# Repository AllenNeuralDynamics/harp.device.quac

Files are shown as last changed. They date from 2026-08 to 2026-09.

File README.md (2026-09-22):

# harp.device.quac
hardware, firmware, and software source files for a Harp-compatible 4-channel Digital-to-Analog Converter.

<p align="center">
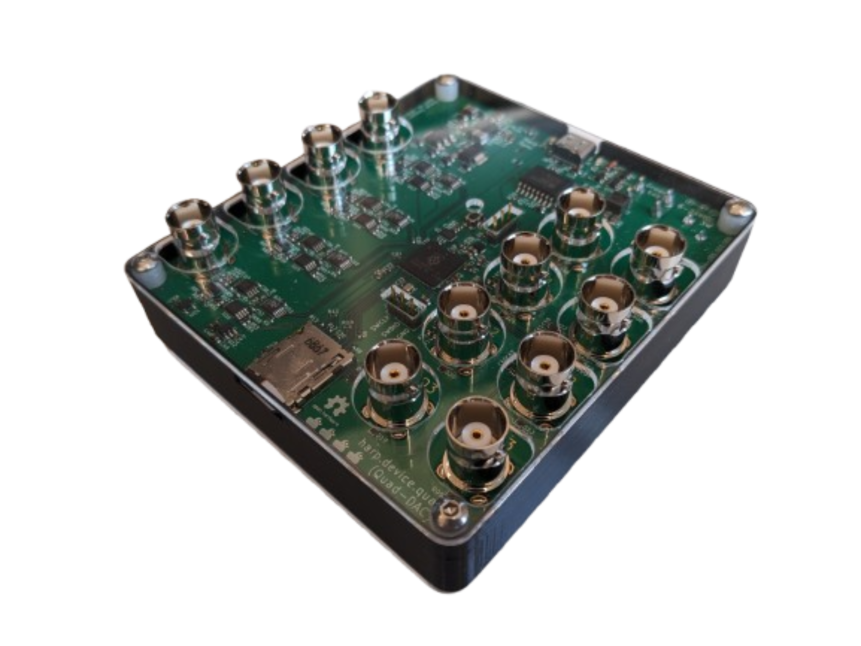
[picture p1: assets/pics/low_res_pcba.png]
  
</p>

## Specs
* Analog Output Channels: 4
* Bit depth: 16-bit
* Update Rate: 2.288 [KHz] to **500 [KHz]** (selectable per-channel)
  * this is the rate at which a new output value is selected.
* Voltage Swing: ±10 [V]
* RMS noise at the zero voltage setting: ~±2.5 [mV]
* absolute deviation from 0 [V]: ±2.5 [mV]
* Power Input: 12-24 [V]
* Power Input Plug: 2.1 x 5.5mm barrel jack (positive center)
* Reverse Polarity protected.
* Additional M4 _ground lug_ provided for de-noising.
* Open source hardware, firmware, and software.
* Cost-effective at < $300 USD to manufacture a single unit.
* Preview the hardware design online with [KiCanvas](https://kicanvas.org/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).
* Enclosure [CAD Model](https://cad.onshape.com/documents/ead77968efe820b4ecd131c1/w/59637a9e969f17bdfb8f8a49/e/516871a36164952787a658eb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)
 
### Trigger Specs
* Trigger options
  * external trigger
  * software trigger
* User-selectable external trigger mapping, i.e: any input trigger can be setup to trigger any number of analog output channels.
* True simultaneous triggering in cases where multiple waveforms are triggered at the same time.
  
### Waveform Player Specs  
The device features 3 ways to play waveforms: either through the two built-in primitive waveform generators or by playing waveforms pre-uploaded to an SD card.

#### File Player Specs  
* Max Data Storage: limited by size of SD card
* Max file length for a single file: 4GB
* File names: user-specifiable with a 32-character limit.
* Format: 16-bit Pulse Code Modulation (PCM)
  * -10 Volts corresponds to 0
  * 0 Volts corresponds to ~32768
  * 10 Volts corresponds to 65535
  
### Harp Specs
The Quac board is a fully Harp-protocol-compliant device built on top of the [Harp Pico Core](https://github.com/harp-tech/core.pico).

* Harp Device ID: 1411
* Harp Events
  * Waveform Start (per-channel)
  * Waveform Finished (per-channel)

## Alternates
The harp.device.quac board follows a legacy of many other devices that came before it.
For similar devices, have a look at:
* [Pulse Pal](https://sanworks.io/shop/viewproduct?productID=1102) by Josh Sanders.
* [PCIE-6738](https://www.ni.com/docs/en-US/bundle/pcie-6738-specs/page/specs.html) by National Instruments.

## Ordering ➡ 💸
Order fully-assembled boards directly from [PCBWay](https://www.pcbway.com/project/shareproject/harp_device_quac_quad_DAC_90dbc413.html).

These printed circuit boards are made on-demand.

## Generating Waveforms ﮩ٨ـﮩﮩ٨ـ
There are two ways to generate waveforms: either with one of two primitive waveform generators or by playing files from the SD card.
These options are referred to as waveform *Player*s.

Setting up and playing a waveform is a simple process for each Analog Output (AO) channel.
1. Specify any external input trigger conditions for the output channel.
2. Specify the waveform Player.
3. Specify the Player's settings.
4. Wait until the Player is ready (< 50[ms] of wait time for the player to apply the settings and arm the waveform).
5. Trigger the Player either via software command or by applying external input to the corresponding external input pins.

For fully worked examples of the above steps, see the examples in the [software](./software) folder.

> [!NOTE]
> While waveforms on the SD card will remain on the card until they are deleted, Player settings for any Player do not persist across device power-cycles or resets.

Player Settings are detailed below for each Player.

### Common Settings
The following settings are common to each Player.
* `cycles`: number of iterations of the current settings (will probably be 1 in most cases).
* `duration_us`: duration in microseconds to play the waveform or 0 to either *play-forever* (if the source is infinite ie: periodic functions) or *play-to-completion* (if the source is finite i.e: files on the SD card).
* `update_frequency_hz`: rate at which samples are produced (max 500 [KHz]).

### SinePlayer Waveforms

#### Settings
* `frequency_hz`: sine wave frequency in hertz
* `amplitude_volts`: "center-to-peak" amplitude in volts
* `vertical_shift_volts`: vertical shift in volts
* `normalized_phase_shift`: period shift normalized to -1.0 (max right shift) to 1.0 (max left shift)

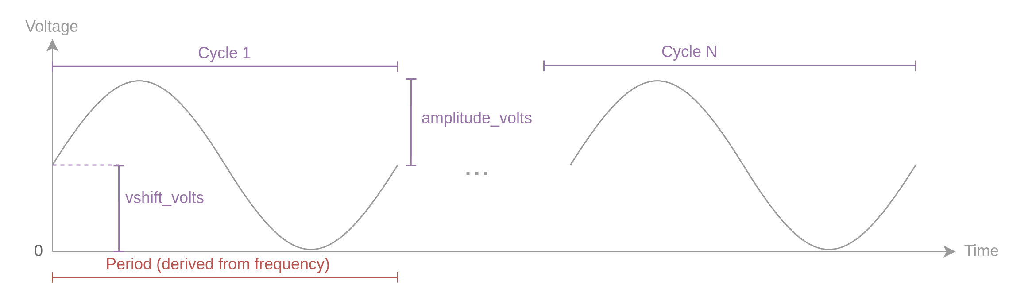
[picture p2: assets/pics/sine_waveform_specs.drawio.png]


#### Example Settings: play a 10Hz sine wave for 3 seconds
| Setting | Value | Note |
|---|---|---|
| `cycles` | 1 | play the following settings once |
| `duration_us` | 3000000 | play for 3 seconds |
| `update_frequency_hz` | 10000 | rate at which to produce new samples |
| `frequency_hz` | 10 | sine wave frequency |
| `amplitude_volts` | 0.5 | result will be 1 [V] peak-to-peak |
| `vertical_shift_volts` | 0.5 | result will span 0 [V] to 1 [V] |
| `normalized_phase_shift` | 0 | no phase shift |

#### Example Settings: play a 10Hz sine wave forever
| Setting | Value | Note |
|---|---|---|
| `cycles` | 1 | |
| `duration_us` | 0 | play forever (until aborted) |
| `update_frequency_hz` | 10000 | |
| `frequency_hz` | 10 | |
| `amplitude_volts` | 0.5 | |
| `vertical_shift_volts` | 0 | |
| `normalized_phase_shift` | 0 | |

### TrapezoidPlayer Waveforms
#### Settings
(Inherits all Common Settings and Sine Player Settings)

* `ramp_on_us`: time in microseconds to rise from lowest to peak value.
* `pulse_width_us`: the total pulse width (including ramp-on and ramp-off duration of the waveform in microseconds.
* `ramp_off_us`: time in microseconds to fall from peak to lowest value.

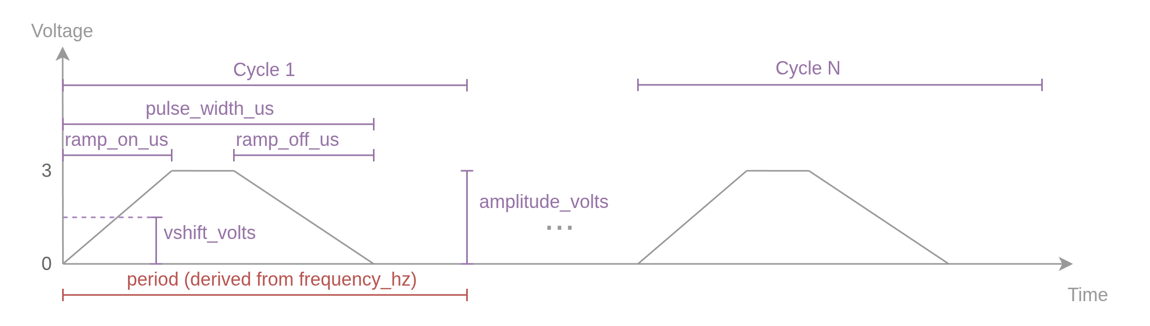
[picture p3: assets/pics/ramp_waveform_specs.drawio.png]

  
### FilePlayer Waveforms from the SD Card 💾

#### Settings
* `path`: filepath on the SD card (32-character limit max)

#### Example Settings: play a file once
| Setting | Value | Note |
|---|---|---|
| `cycles` | 1 | play the following settings once |
| `duration_us` | 0 | play the file to completion |
| `update_frequency_hz` | 500000 | max update rate (might be different depending on file). |
| `path` | channel_0.bin | assumes this file exists at the top level folder in the SD card |

#### Example Settings: play a file multiple times
| Setting | Value | Note |
|---|---|---|
| `cycles` | 3 | loop back and play the entire file 3 times |
| `duration_us` | 0 | |
| `update_frequency_hz` | 500000 | |
| `path` | channel_0.bin | |

The _quac_ board reads files in 16-bit little-endian _Pulse-Code Modulation_ (PCM) format.
There are a few options for generating waveforms in this format.

#### Upscaling Existing Files 💽
It's possible to convert existing audio files to a format compatible with the _quac_ board using `ffmpeg`.
To upscale an existing _\*.wav_ file to a 500KHz update rate, use:
```bash
ffmpeg -i example.wav -f u16le -ar 500000 output.raw
```

#### With numpy 💻
For more complicated waveforms that do not derive from an existing audio file, we recommend using numpy.

Here's an example that generates the [North American Ringing Tone](https://en.wikipedia.org/wiki/Ringing_tone#Bell_System_tones), which is the sum of a 440Hz and 480Hz sine wave.

```python
import numpy as np

NUM_SAMPLES = int(5e6) # 5 million samples @ 500KSs -> 10 seconds of data.
SAMPLES_PER_SECOND = 500000.
FULL_SCALE_RANGE = (1 << 16) - 1 # 16 bit resolution
SECONDS = NUM_SAMPLES/SAMPLES_PER_SECOND
FILENAME = f"channel_0.bin"

t = np.linspace(0, SECONDS, NUM_SAMPLES)
x = np.zeros(NUM_SAMPLES)

# make sine wave. offset it to uint16 range: 0-65535
for freq in [440, 480]:
    x += (np.sin(2 * np.pi * freq * t)+1)/2 * FULL_SCALE_RANGE/2

# Write result to file in 16-bit little-endian format.
with open(FILENAME, "wb") as file:
    x.astype("<u2").tofile(file)

```

#### Uploading Waveforms ♒︎➝💾
Currently waveforms must be uploaded to the SD card manually.

> [!WARNING]
> Power down the device before removing or inserting the SD card.

## Playing Waveforms 🎶
There are two ways to trigger a configured waveform to play: via software command or through the device's external triggers labeled **DI0**, **DI1**, **DI2**, and **DI3**.

Before triggering a waveform, you must

### Software Triggering
For fully worked examples in both Bonsai and Python, see the [software examples folder](./software).

### External Triggering
By default the device's power-on-reset behavior is setup to:
setup external triggers such that pins _DIO_ - _DI3_ correspond to playing output pins _A0_ - _A3_ respectively.

Trigger mapping is configurable!
Any input trigger can be configured to trigger any number of outputs.
To alter the trigger mapping, you must use software commands through either Bonsai or Python.

## Compatible SD Cards 💾
During normal operation, up-to-four waveforms stored on the SD card are read (interleaved) at 4MB per second.
With the extra overhead of switching between files, the SD card must be able to support read speeds ≥8MB per second.
In theory, any _Class 10 SD Card_ formatted in _FAT32 format_ should be compatible.

But since card performance can vary, here's a list of tested cards:
| Vendor | Model |
|---|---|
| Samsung | Pro Plus 8GB Smart Card |
| GIGASTONE | Industrial 8GB MLC |
| | |

## Working Principle
The following section details how the underlying firmware generates waveforms.

### Selectable Player Architecture
Each channel features a modular approach to dividing up the work of playing waveforms.
<p align="center">
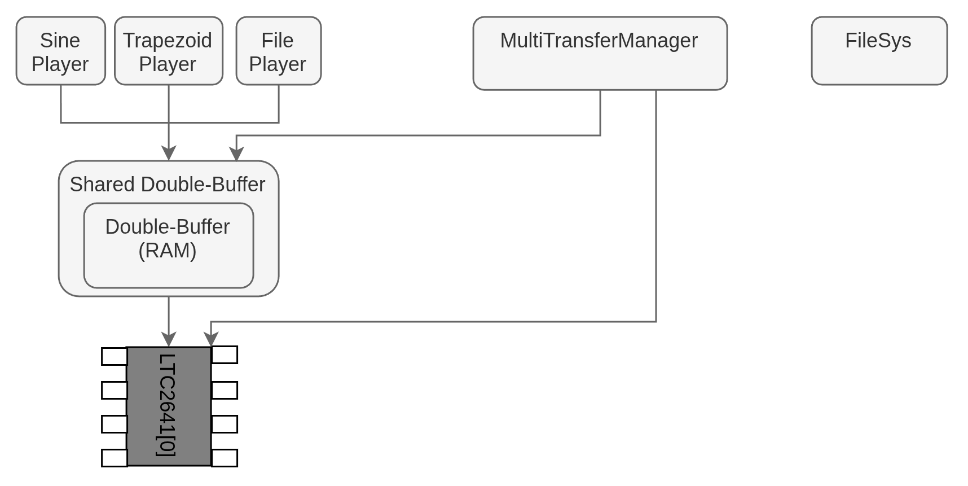
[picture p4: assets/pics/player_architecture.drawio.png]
  
</p>

The level closest to the hardware is a driver that wraps a custom PIO program to communicate over SPI to each LTC2641 DAC chip.

The next stage up is a shared double buffer and two DMA channels responsible for ensuring that the driver receives an uninterrupted, steady stream of bytes paced by a DMA Timer setup to match the user-requested playback rate.
Inspecting the state of the double buffer is implemented by reading single registers native to the Pico's DMA peripherals to eliminate the need to implement mutex locks to check multiple locations in memory concurrently.

The layer above features one of multiple ways of generating data.
These _Players_ are responsible for producing a sequence of bytes up to the limits specified by the user's waveform settings.
Each _Player_ is derived from a base class that manages sending data to the corresponding available buffer from the downstream double buffer and manages sequence arming and termination.

In the full architecture, four copies of the above pipeline exist like so:

<p align="center">
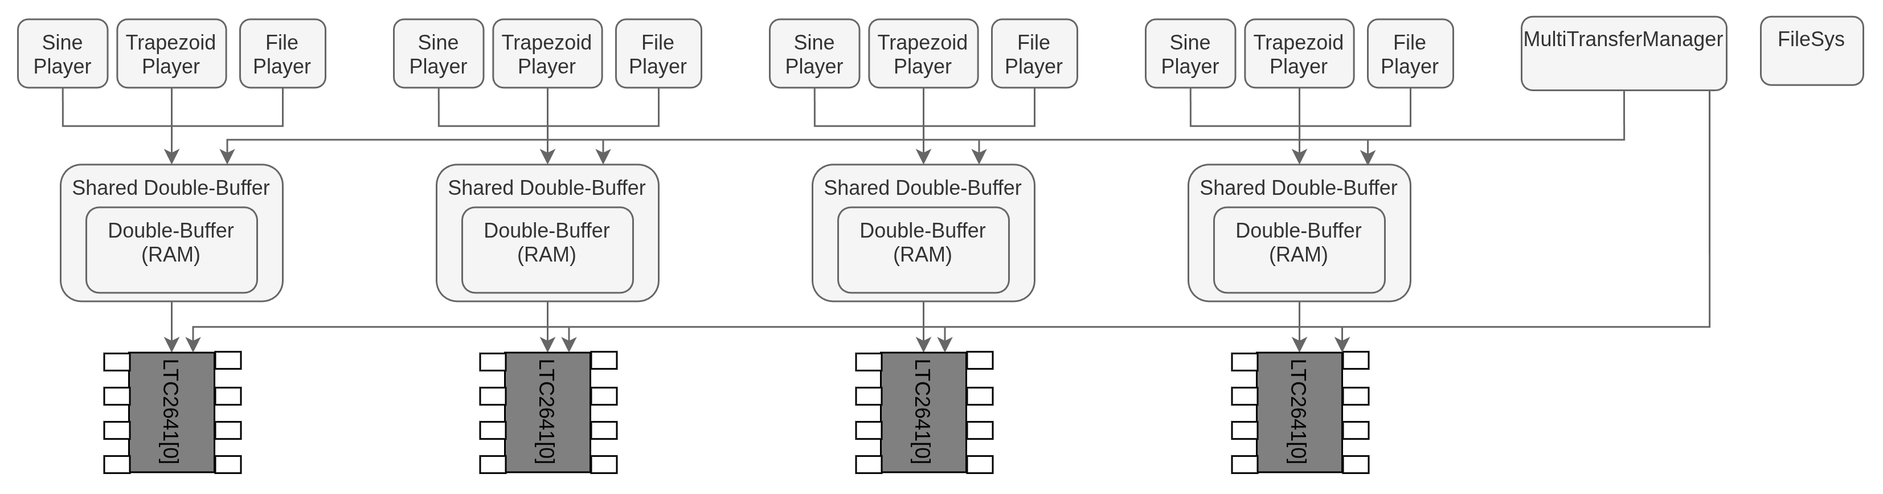
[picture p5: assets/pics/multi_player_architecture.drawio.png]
  
</p>

The `MultiTransferManager` connects to each double buffer and driver and handles triggering an armed transfer, and it guarantees that multiple simultaneous requests to start a transfer occur simultaneously.

### FilePlayer Streaming Pipeline
Waveforms are read interleaved from their sources in "chunks" of 16384 samples at a time and then pushed into double buffers such that the resulting output plays waveforms concurrently without interruption.

Buffer size was selected to be large enough such that data from the SD card is can be read faster than it needs to sent to the downstream DAC drivers.
This setup was tested in the worst-case scenario where 4 files are being read at once.

A single CPU core is dedicated to this task of reading waveform sources and topping off buffers while the other core handles Harp communication, settings configuration, and waveform start/stop inputs.

<p align="center">
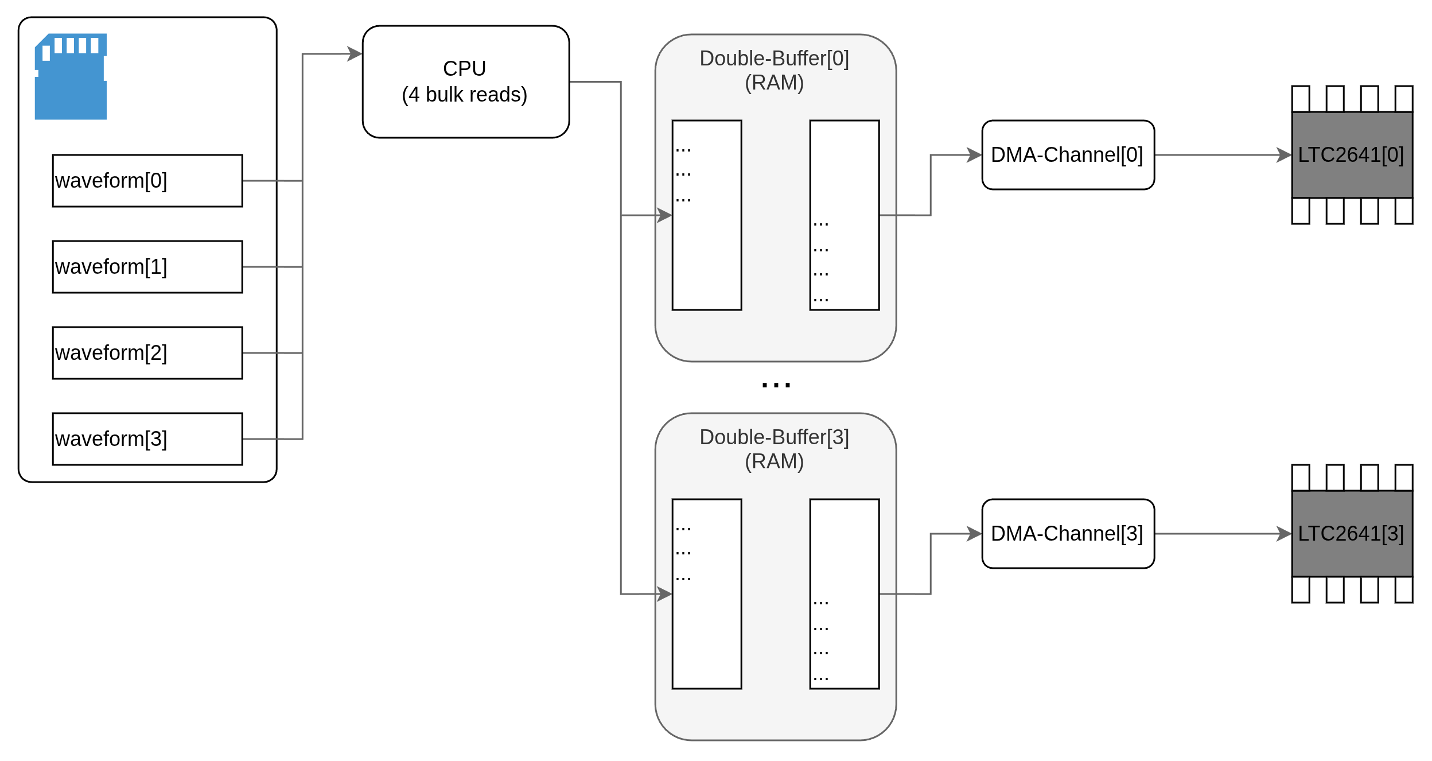
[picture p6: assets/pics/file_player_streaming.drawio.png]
  
</p>

## Updating the Firmware
New firmware is available on the [Releases Page](https://github.com/AllenNeuralDynamics/harp.device.quac/releases).
To upload new firmware to the device, do the following:
1. Ensure that the board is connected to a PC with the USB cable.
1. Power down the board. (Note that power comes from the barrel jack, _not_ the USB cable.)
2. Power on the board with the _BOOTSEL_ button held down. Then release the BOOTSEL button once the board has been powered up. The device will now appear on the connected PC as a flash drive. See the figure below to identify the BOOTSEL button. You may need to use a hex key to access this button with the case lid attached. 
<p align="center">
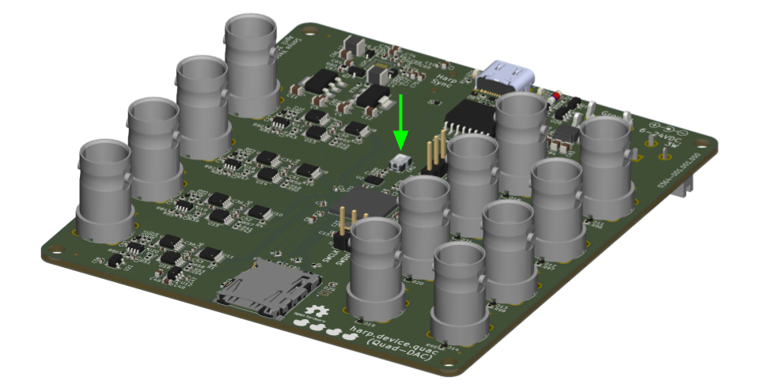
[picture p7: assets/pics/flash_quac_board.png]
  
</p>

4. Drag and drop the **\*.uf2** firmware file into the flash drive's top level directory. The flash drive should disappear indicating that the firmware upload worked. The device now has new firmware.

## Known Limitations
Currently the device has some known limits, most of which are planned to be eclipsed by future firmware releases.
This non-comprehensive list includes:
* [FilePlayer cannot deterministically play a subset of a file multiple times](https://github.com/AllenNeuralDynamics/harp.device.quac/issues/100)
* [Waveforms cannot yet be uploaded to the SD card directly over USB](https://github.com/AllenNeuralDynamics/harp.device.quac/issues/6)

For a full list of issues, head over to the project's [issues page](https://github.com/AllenNeuralDynamics/harp.device.quac/issues).

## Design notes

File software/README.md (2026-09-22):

# Software Interfaces

The following software interfaces for both Bonsai and Python are auto-generated from this project's [device.yml](../device.yml) using the [Harp Toolkit](https://github.com/harp-tech/toolkit) command line utility.

Do not edit these interfaces directly.
Instead, to update these packages, update the device.yml first and then follow the Toolkit's [code generation instructions](https://github.com/harp-tech/toolkit#code-generation).

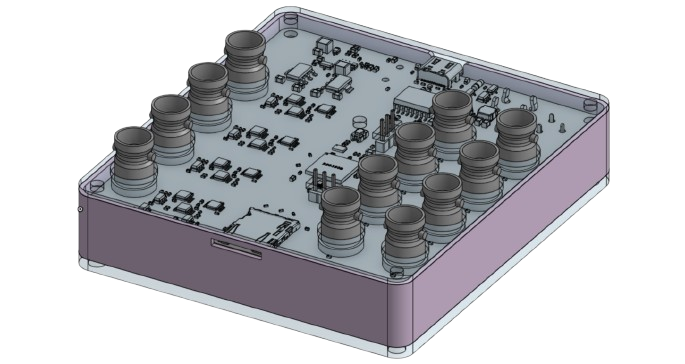
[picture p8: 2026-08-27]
assets/pics/cad_mockup.png

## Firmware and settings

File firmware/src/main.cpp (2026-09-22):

#include <array>
#include <cstring>
#include "core1_file_player.h"
#include "dma_double_buffer.h"
#include "file_player.h"
#include "sine_wave_player.h"
#include "trapezoid_player.h"
#include "multi_transfer_manager.h"
#include "harp_c_app.h"
#include "harp_synchronizer.h"
#include "config.h"
#include "quac_app.h"
#include "pio_ltc264x.h"
#include "pico/multicore.h"
#ifdef DEBUG
    #include <cstdio> // for printf
    #include "pico/stdlib.h" // for uart printing
#endif

const uint8_t interface_hash[20] = INTERFACE_HASH;

// Create Harp App.
HarpCApp& app = HarpCApp::init(HARP_DEVICE_ID, FW_VERSION, HW_VERSION, "quac",
                               (uint8_t*)GIT_HASH, interface_hash,
                               app_reg_specs, APP_REG_COUNT,
                               update_app, reset_app);

std::array<PIO_LTC264x, NUM_CHANNELS> dacs
{{
    {pio2, DAC_PINS[0].sck, DAC_PINS[0].pico},
    {pio2, DAC_PINS[1].sck, DAC_PINS[1].pico, false, dacs[0].get_offset()},
    {pio2, DAC_PINS[2].sck, DAC_PINS[2].pico, false, dacs[0].get_offset()},
    {pio2, DAC_PINS[3].sck, DAC_PINS[3].pico, false, dacs[0].get_offset()},
}};

std::array<FilePlayer<T, READ_BUF_SIZE>, NUM_CHANNELS> file_players{};
std::array<SinePlayer<T, READ_BUF_SIZE>, NUM_CHANNELS> sine_players{};
std::array<TrapezoidPlayer<T, READ_BUF_SIZE>, NUM_CHANNELS> trapezoid_players{};

std::array<TimerPacedDMADoubleBuffer<T, READ_BUF_SIZE>, NUM_CHANNELS> bufs
{{
    {dacs[0].get_tx_fifo_address()},
    {dacs[1].get_tx_fifo_address()},
    {dacs[2].get_tx_fifo_address()},
    {dacs[3].get_tx_fifo_address()}
}};

std::array<DMADoubleBuffer<T, READ_BUF_SIZE>*, NUM_CHANNELS> buf_ptrs
{{ &bufs[0], &bufs[1], &bufs[2], &bufs[3] }};

/// Aggregate for iterating overall all players via a base class pointer
std::array<SourcePlayer<T, READ_BUF_SIZE>*, NUM_CHANNELS * NUM_PLAYER_TYPES>
player_ptrs;

MultiTransferManager<T, READ_BUF_SIZE, NUM_CHANNELS> transfer_manager(buf_ptrs,
                                                                      dacs);

void set_led(bool enabled)
{    gpio_put(DEBUG_LEDS[0], enabled);}

bool get_led()
{    return gpio_get(DEBUG_LEDS[0]);}

// Core0 main.
int main()
{
// Configure OP_LED
    gpio_init(DEBUG_LEDS[0]);
    gpio_set_dir(DEBUG_LEDS[0], GPIO_OUT);
    gpio_put(DEBUG_LEDS[0], 0);
// Init Synchronizer.
    HarpSynchronizer::init(uart1, HARP_SYNC_RX_PIN);
    app.set_synchronizer(&HarpSynchronizer::instance());
    app.set_op_led_fns(set_led, get_led);
#ifdef DEBUG
    stdio_uart_init_full(uart0, 921600, UART_TX_PIN, -1); // use uart1 tx only.
    printf("Hello, from the quac board!\r\n");
#endif
    queue_init(&ext_trigger_event_queue, sizeof(ext_trigger_event_t), 32);
    // Populate player_ptrs.
    size_t index = 0;
    for (auto& file_player: file_players) player_ptrs[index++] = &file_player;
    for (auto& sine_player: sine_players) player_ptrs[index++] = &sine_player;
    for (auto& trapz_player: trapezoid_players) player_ptrs[index++] = &trapz_player;
    // Mount the file system.
    FATFS fs;
    FRESULT fr = f_mount(&fs, "", 1);
    // Setup DACs first.
    for (const auto& dac: dacs)
        dac.start();
    reset_app();
    while (true)
        app.run();
}

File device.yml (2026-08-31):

%YAML 1.1
---
# yaml-language-server: $schema=https://harp-tech.org/draft-02/schema/device.json
device: Quac
whoAmI: 1411
firmwareVersion: "0.1"
hardwareTargets: "1.1"

registers:
  DOPortState:
    address: 32
    type: U8
    access: Write
    maskType: DigitalOutputs
    description: Reflects and specifies the state of the digital output lines.
  DOPortSet:
    address: 33
    type: U8
    access: Write
    maskType: DigitalOutputs
    description: Sets the digital output lines specified in the mask to logic HIGH.
  DOPortClear:
    address: 34
    type: U8
    access: Write
    maskType: DigitalOutputs
    description: Clears the digital output lines specified in the mask to logic LOW.

  ExternalTriggerState:
    address: 35
    type: U8
    access: Read
    maskType: DigitalInputs
    description: Reflects the raw state of the external trigger input lines.

  AOPortState:
    address: 36
    type: Float
    length: 4
    access: Write
    description: >-
      Reflects and specifies the output voltage of all four analog output
      channels in volts. Reads and writes fail with an error unless every
      channel is idle, since a channel playing a preset waveform owns its
      output value.
    payloadSpec:
      AOChannel0:
        offset: 0
        description: The output voltage of analog output channel 0 in volts.
      AOChannel1:
        offset: 1
        description: The output voltage of analog output channel 1 in volts.
      AOChannel2:
        offset: 2
        description: The output voltage of analog output channel 2 in volts.
      AOChannel3:
        offset: 3
        description: The output voltage of analog output channel 3 in volts.

  AOChannel0: &aoChannel
    address: 37
    type: Float
    access: Write
    minValue: -10
    maxValue: 10
    defaultValue: 0
    description: >-
      Reflects and specifies the output voltage of analog output channel 0 in
      volts. Writes fail with an error while this channel is playing a preset
      waveform, and reads fail with an error while any channel is playing a
      preset waveform.
  AOChannel1:
    <<: *aoChannel
    address: 38
    description: >-
      Reflects and specifies the output voltage of analog output channel 1 in
      volts. Writes fail with an error while this channel is playing a preset
      waveform, and reads fail with an error while any channel is playing a
      preset waveform.
  AOChannel2:
    <<: *aoChannel
    address: 39
    description: >-
      Reflects and specifies the output voltage of analog output channel 2 in
      volts. Writes fail with an error while this channel is playing a preset
      waveform, and reads fail with an error while any channel is playing a
      preset waveform.
  AOChannel3:
    <<: *aoChannel
    address: 40
    description: >-
      Reflects and specifies the output voltage of analog output channel 3 in
      volts. Writes fail with an error while this channel is playing a preset
      waveform, and reads fail with an error while any channel is playing a
      preset waveform.

  DacReady:
    address: 41
    type: U8
    access: Read
    maskType: AnalogOutputs
    description: Reflects which analog output channels are configured and ready to start.
  DacStart:
    address: 42
    type: U8
    access: [Write, Event]
    maskType: AnalogOutputs
    description: >-
      Starts the waveform player on the ready analog output channels specified
      in the mask. Events from this register report the channels that were
      started by an external trigger.
  DacPause:
    address: 43
    type: U8
    access: Write
    maskType: AnalogOutputs
    description: Pauses the channels set in the mask and resumes those cleared in it.
  DacAbort:
    address: 44
    type: U8
    access: Write
    maskType: AnalogOutputs
    description: Aborts waveform playback on the analog output channels specified in the mask.
  DacFinished:
    address: 45
    type: U8
    access: Event
    maskType: AnalogOutputs
    description: Reports which analog output channels have finished playing their waveform.

  ChannelExternalTriggers0: &channelExternalTriggers
    address: 46
    type: U8
    access: Write
    maskType: DigitalInputs
    description: Specifies which external trigger lines can start channel 0.
  ChannelExternalTriggers1:
    <<: *channelExternalTriggers
    address: 47
    description: Specifies which external trigger lines can start channel 1.
  ChannelExternalTriggers2:
    <<: *channelExternalTriggers
    address: 48
    description: Specifies which external trigger lines can start channel 2.
  ChannelExternalTriggers3:
    <<: *channelExternalTriggers
    address: 49
    description: Specifies which external trigger lines can start channel 3.
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

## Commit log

2025-11-25 move core.pico to lib folder
2025-12-02 draft simplified rp2350 schematic w/sd card
    [Communication.kicad_sch, Core_RP2350.kicad_sch, Input.kicad_sch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]
2025-12-03 draft new analog signal chain & short-circuit detection
    [Communication.kicad_sch, Core_RP2350.kicad_sch, DACs.kicad_sch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]
2025-12-04 draft split rail power supply design
    [Core_RP2350.kicad_sch, DACs.kicad_sch, Input.kicad_sch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]
2025-12-05 cleanup power supply chain
    [Core_RP2350.kicad_sch, Input.kicad_sch, Output.kicad_sch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]
2025-12-05 add note in schematic
    [SC_Detection.kicad_sch]
2025-12-11 update tvs diodes, regulators, and power supply chain
    [Core_RP2350.kicad_sch, DACs.kicad_sch, Input.kicad_sch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]
2025-12-13 update short detection; draft bom
    [Core_RP2350.kicad_sch, DACs.kicad_sch, Input.kicad_sch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]
2025-12-17 update board draft
    [Core_RP2350.kicad_sch, DACs.kicad_sch, Input.kicad_sch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]
2025-12-18 draft power pours in internal layers
    [Core_RP2350.kicad_sch, SC_Detection.kicad_sch, harp.device.quad.dac.kicad_pcb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]
2025-12-21 update pcb draft
    [Core_RP2350.kicad_sch, Power_Supply.kicad_sch, harp.device.quad.dac.kicad_pcb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]
2025-12-22 update pcb
    [Core_RP2350.kicad_sch, DACs.kicad_sch, harp.device.quad.dac.kicad_pcb]
2025-12-23 fix sd card order; finish pcb draft
    [Core_RP2350.kicad_sch, Power_Supply.kicad_sch, SC_Detection.kicad_sch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]
2025-12-23 update bom
    [Core_RP2350.kicad_sch, DACs.kicad_sch, Power_Supply.kicad_sch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]
2025-12-31 update footprints to meet min pad clearance of 0.2mm
    [Core_RP2350.kicad_sch, DACs.kicad_sch, Input.kicad_sch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]
2026-01-03 update missing footprints to meet min pad mask clearance
    [SC_Detection.kicad_sch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]
2026-01-05 add bootsel switch 3d model
    [harp.device.quad.dac.kicad_pcb]
2026-01-26 update incorrect part numbers to match correct footprints
    [Core_RP2350.kicad_sch, DACs.kicad_sch, Input.kicad_sch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]
2026-08-27 Dev -> Main (#85)
    * draft dma double buffer
    * cleanup dma double buffer draft
    * draft double buffer
    * redraft dma double buffer
    * get ping pong re-triggering
    * draft double buffer with example
    * get buffer -> dma-> pio working
    * draft sd card to dac for 1 channel
    * get single chan sd-to-dac working
    * redraft file iteration with linked list
    * get large transfers working
    * draft multichannel sd -> dma -> dac
    * cleanup 4 channel sd to dac example
    * update pio ltc264x lib
    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
    [Core_RP2350.kicad_sch, DACs.kicad_sch, Input.kicad_sch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]
2026-08-31 Dev (#110)
    * add pause/resume with test
    * valdiate abort_transfer fn
    * draft MultiFilePlayer
    * draft multi file player class
    * add/test is_aborted and reset_transfer_config after abort
    * update abort example
    * draft test for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
    [abort.py, device.yml, dma_double_buffer.h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]
2026-09-04 Fix end of transfer race (#115)
    * check idle buffer only in update loop
    * fix erroneous buffer stuffing before last dma transfer
    * remove gpio toggling
    [dma_double_buffer.h, quac_app.cpp]
2026-09-04 Update readme with cad model link
2026-09-22 upate pico core (#117)
    * upate pico core
    * add readme with notes on software interface generation
    * update python examples
    * add pcbway link
    * firmware version bump
    * cleanup sine sweep example
2026-10-17 Blankety Blank (#124)
    * draft blanking feature
    * update device.yml
    * draft muting/unmuting
    * add valid-settings check for pins controlled via blanking
    * cleanup blanking draft
    * remove references to single-function external trigger pins
    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
2026-10-19 Refactor device.yml to the device interface style guide and regenerate clients (#126)
    * Clean up device.yml against suggested style
    * Update tool reference
    * Remove defaults
    * Rebuild
    * Modify register name for consistency
    * Bump version
    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
2026-10-30 DI Pin Inversion and DO Tracking (#128)
    * update gitignore
    * update device.yml and fw with stub interface for DO functionality
    * enable transfer manager to add user-specified end-of-transfer callback
    * draft do tracking
    * draft digital input port inversion feature
    * bump major fw version number
    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
